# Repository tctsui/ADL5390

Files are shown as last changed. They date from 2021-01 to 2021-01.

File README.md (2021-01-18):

# ADL5390
This is a PCB design for an RF vector multiplier ADL5390 from Analog Devices. The functionality and design of this board is similar to the original evaluation board design. The purpose of this board is to solve the problem of crosstalk between the I-channel and the Q-channel in the original evaluation board. The main modification is the use of differential inputs on the two-channels with  a 180 hybrid coupler SYPJ-2-33+.
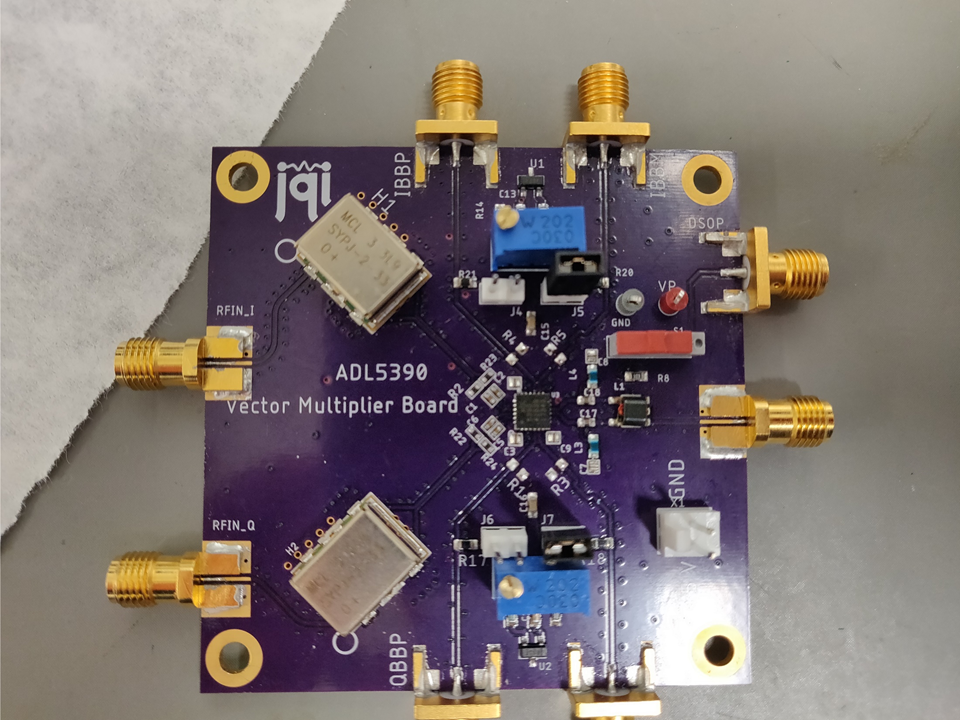
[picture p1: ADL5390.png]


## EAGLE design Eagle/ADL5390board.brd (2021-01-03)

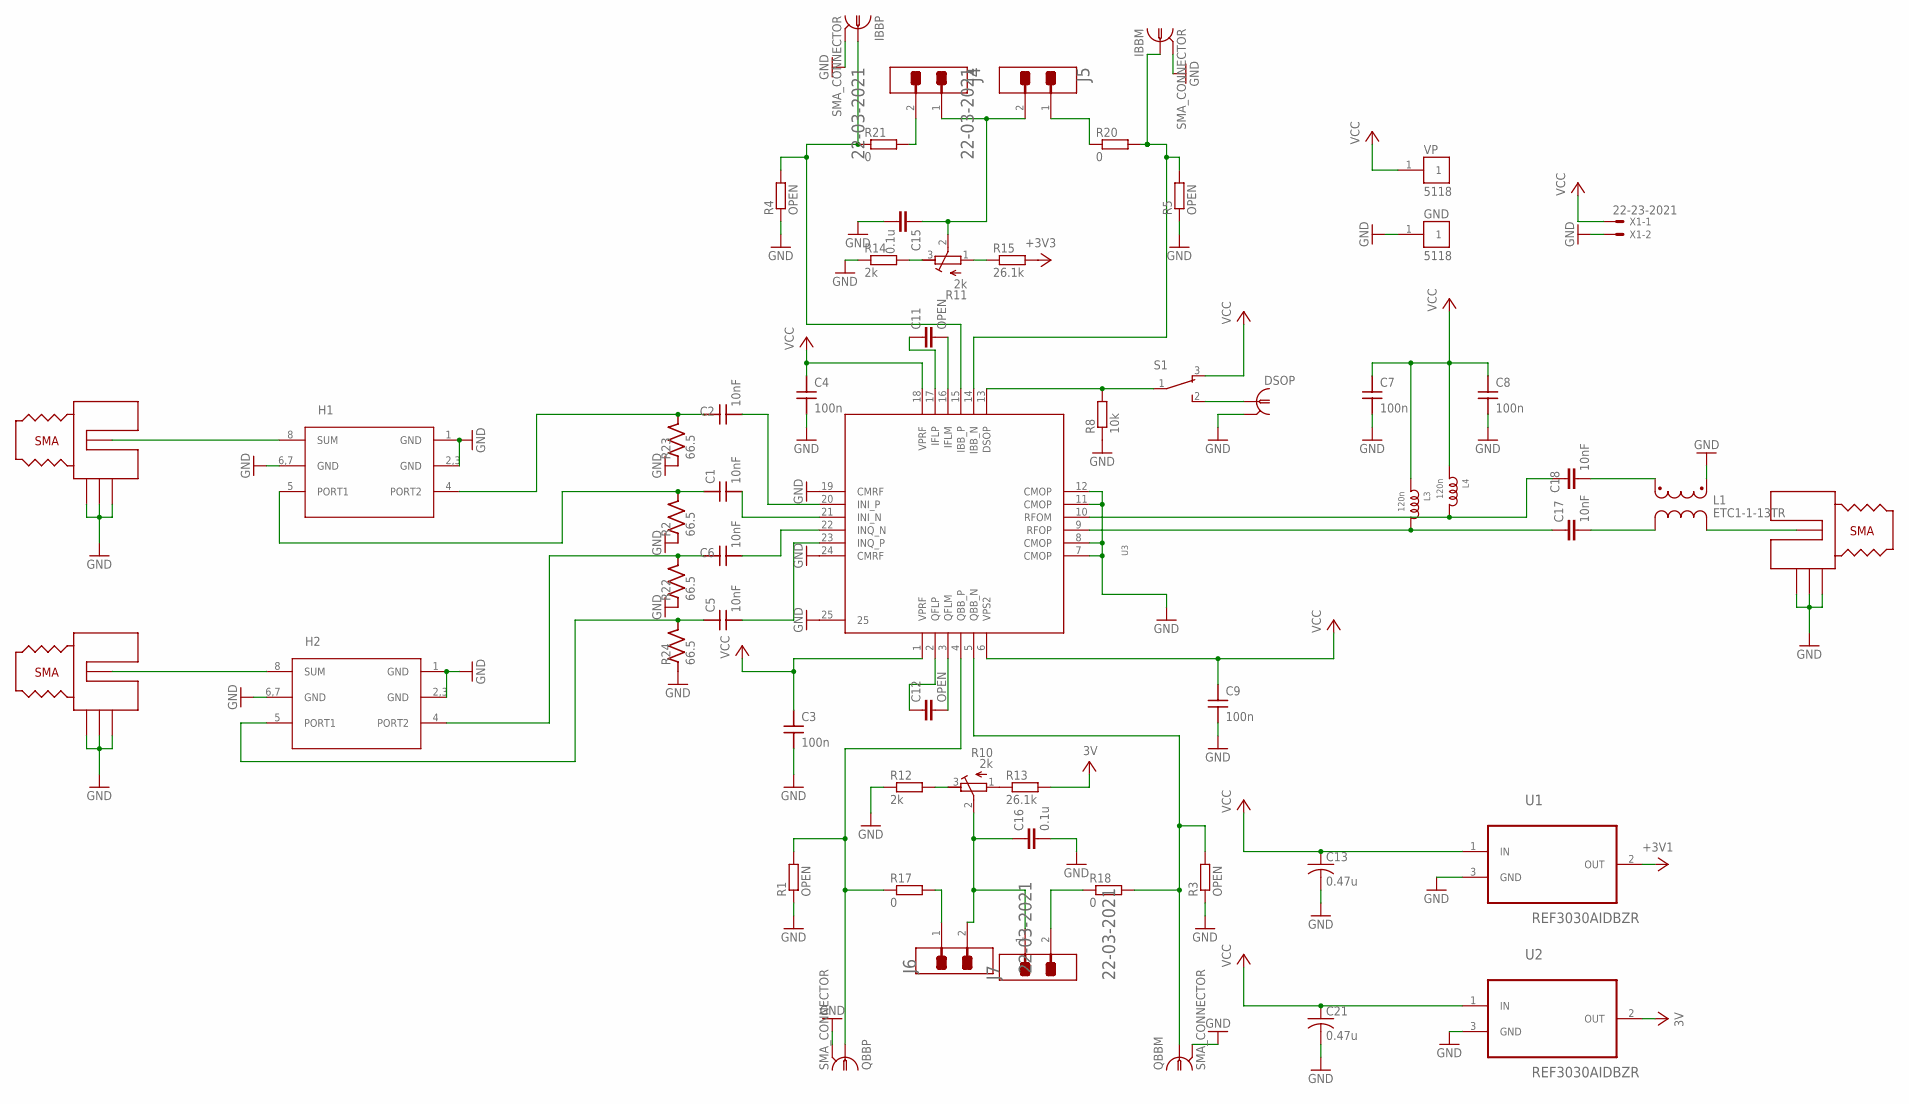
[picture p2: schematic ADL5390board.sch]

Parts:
C1, C2, C5, C6: 10nF; C_MLCC_0402; PARTNO C1005C0G1H102J050BA; DIGIKEY 445-6846-1-ND
C3, C4, C7, C8, C9: 100n; C_MLCC_0204; PARTNO EWK105C6104MPHF; DIGIKEY 587-5138-1-ND
C11, C12: OPEN; C0603
C13, C21: 0.47u; C0603; PARTNO CL10B474KA8NFNC; DIGIKEY 1276-2082-1-ND
C15, C16: 0.1u; C0603; PARTNO CL10B104KA8NNNC; DIGIKEY 1276-1006-1-ND
C17, C18: 10nF; C0402; PARTNO C1005C0G1H102J050BA; DIGIKEY 445-6846-1-ND
DSOP: SMA_CONNECTOR; QKDLAB_JOSH_MECHANICAL_JOHNSON_SMA_EDGE_LAUNCH_142-0701-851
GND: 5118; TP_5118; PARTNO 5118; DIGIKEY 36-5118-ND
H1, H2: SYPJ-2-33+; PL-274
IBBM: SMA_CONNECTOR; QKDLAB_JOSH_MECHANICAL_JOHNSON_SMA_EDGE_LAUNCH_142-0701-851; DIGIKEY J658-ND
IBBP: SMA_CONNECTOR; QKDLAB_JOSH_MECHANICAL_JOHNSON_SMA_EDGE_LAUNCH_142-0701-851; DIGIKEY J658-ND
J1, J2, J3: QKDLAB_JOSH_MECHANICAL_JOHNSON_SMA_18GHZ_142-0761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; QKDLAB_JOSH_MECHANICAL_JOHNSON_SMA_18GHZ_4-LAYER_142-0761-8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; PARTNO 901-10511-2; DIGIKEY ARF2499-ND
J4, J5, J6, J7: MOLEX_22-03-2021MOLEX_22-03-2021_0_0; MOLEX_22-03-2021_0
L1: ETC1-1-13TR; SM22; DIGIKEY 1465-1217-1-ND
L3, L4: 120n; R0603; PARTNO LQW18ASR12G0CD; DIGIKEY 490-LQW18ASR12G0CDCT-ND
QBBM: SMA_CONNECTOR; QKDLAB_JOSH_MECHANICAL_JOHNSON_SMA_EDGE_LAUNCH_142-0701-851; DIGIKEY J658-ND
QBBP: SMA_CONNECTOR; QKDLAB_JOSH_MECHANICAL_JOHNSON_SMA_EDGE_LAUNCH_142-0701-851; DIGIKEY J658-ND
R1, R3, R4, R5: OPEN; R0603; PARTNO CRCW06030000Z0EA; DIGIKEY 541-0.0GCT-ND
R2, R22, R23, R24: 66.5; R_0402; PARTNO ERJ-2RKF66R5X; DIGIKEY P66.5LDKR-ND
R8: 10k; R0603; PARTNO ERA-3AEB103V; DIGIKEY P10KDBCT-ND
R10, R11: 2k; RTRIM3296W; PARTNO PV36W202C01B00; DIGIKEY 490-2880-ND
R12, R14: 2k; R0603; PARTNO ERA-3AEB202V; DIGIKEY P2.0KDBCT-ND
R13, R15: 26.1k; R0603; PARTNO ERA-3AEB2612V; DIGIKEY P26.1KDBCT-ND
R17, R18, R20, R21: 0; R0603; PARTNO CRCW06030000Z0EA; DIGIKEY 541-0.0GCT-ND
S1: 450301014042; DIGIKEY 450301014042-ND
U1, U2: REF3030AIDBZR; SOT95P237X112-3N
U3: ADL5390_ADL5390; PARTNO ADL5390ACPZ-REEL7; DIGIKEY ADL5390ACPZ-REEL7CT-ND
VP: 5118; TP_5118; PARTNO 5000; DIGIKEY 36-5000-ND
X1: 22-23-2021

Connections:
+3V3: R15.2, U1.2 (OUT)
DSOP: R8.2, S1.1, U3.13 (DSOP)
GND: C3.P$2 (2), C4.P$2 (2), C7.P$2 (2), C8.P$2 (2), C9.P$2 (2), C13.2, C15.2, C16.2, C21.2, DSOP.P$2 (2), DSOP.P$3 (2), DSOP.P$4 (2), DSOP.P$5 (2), GND.1, H1.1 (GND), H1.2,3 (GND), H1.6,7 (GND), H2.1 (GND), H2.2,3 (GND), H2.6,7 (GND), IBBM.P$2 (2), IBBM.P$3 (2), IBBM.P$4 (2), IBBM.P$5 (2), IBBP.P$2 (2), IBBP.P$3 (2), IBBP.P$4 (2), IBBP.P$5 (2), J1.P$2 (GND), J1.P$3 (GND), J1.P$4 (GND), J2.P$2 (GND), J2.P$3 (GND), J2.P$4 (GND), J3.P$2 (GND), J3.P$3 (GND), J3.P$4 (GND), L1.1, QBBM.P$2 (2), QBBM.P$3 (2), QBBM.P$4 (2), QBBM.P$5 (2), QBBP.P$2 (2), QBBP.P$3 (2), QBBP.P$4 (2), QBBP.P$5 (2), R1.1, R2.P$1 (1), R3.1, R4.1, R5.1, R8.1, R12.1, R14.1, R22.P$1 (1), R23.P$1 (1), R24.P$1 (1), U1.3 (GND), U2.3 (GND), U3.7 (CMOP), U3.8 (CMOP), U3.11 (CMOP), U3.12 (CMOP), U3.19 (CMRF), U3.24 (CMRF), U3.25, X1.2
IBB_N: IBBM.P$1 (1), R5.2, R20.2, U3.14 (IBB_N)
IBB_P: IBBP.P$1 (1), R4.2, R21.1, U3.15 (IBB_P)
IFL_N: C11.2, U3.16 (IFLM)
IFL_P: C11.1, U3.17 (IFLP)
INI_N: C1.P$2 (2), U3.21 (INI_N)
INI_P: C2.P$2 (2), U3.20 (INI_P)
INQ_N: C6.P$2 (2), U3.22 (INQ_N)
INQ_P: C5.P$2 (2), U3.23 (INQ_P)
IN_N: H2.8 (SUM), J2.P$1 (SIG)
IN_P: H1.8 (SUM), J1.P$1 (SIG)
unnamed: R11.1 (A), R15.1
unnamed: R11.3 (E), R14.2
unnamed: C15.1, J4.1, J5.2, R11.2 (S)
unnamed: J4.2, R21.2
unnamed: J5.1, R20.1
unnamed: J6.1, R17.2
unnamed: J7.2, R18.1
unnamed: C16.1, J6.2, J7.1, R10.2 (S)
unnamed: R10.3 (E), R12.2
unnamed: R10.1 (A), R13.1
unnamed: C18.2, L1.5
unnamed: C17.2, L1.4
unnamed: J3.P$1 (SIG), L1.3
unnamed: DSOP.P$1 (1), S1.2
QBB_N: QBBM.P$1 (1), R3.2, R18.2, U3.5 (QBB_N)
QBB_P: QBBP.P$1 (1), R1.2, R17.1, U3.4 (QBB_P)
QFL_N: C12.2, U3.3 (QFLM)
QFL_P: C12.1, U3.2 (QFLP)
RFINI_N: C1.P$1 (1), H1.5 (PORT1), R2.P$2 (2)
RFINI_P: C2.P$1 (1), H1.4 (PORT2), R23.P$2 (2)
RFINQ_N: C6.P$1 (1), H2.4 (PORT2), R22.P$2 (2)
RFINQ_P: C5.P$1 (1), H2.5 (PORT1), R24.P$2 (2)
RFO_N: C18.1, L4.2, U3.10 (RFOM)
RFO_P: C17.1, L3.2, U3.9 (RFOP)
V+: R13.2, U2.2 (OUT)
VCC: C3.P$1 (1), C4.P$1 (1), C7.P$1 (1), C8.P$1 (1), C9.P$1 (1), C13.1, C21.1, L3.1, L4.1, S1.3, U1.1 (IN), U2.1 (IN), U3.1 (VPRF), U3.6 (VPS2), U3.18 (VPRF), VP.1, X1.1

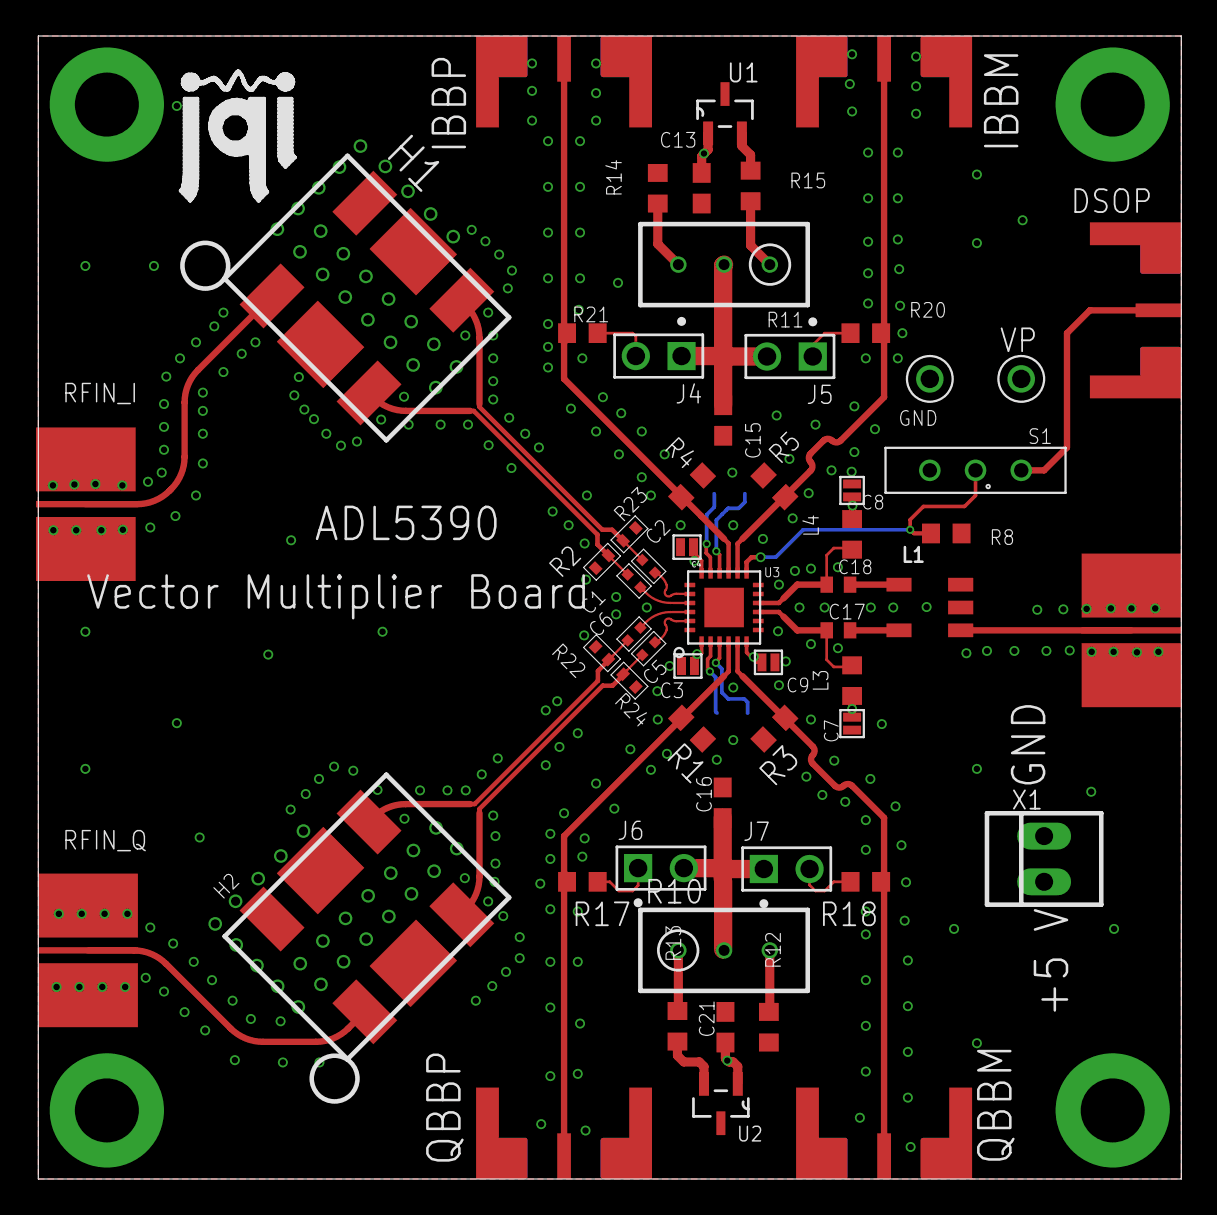
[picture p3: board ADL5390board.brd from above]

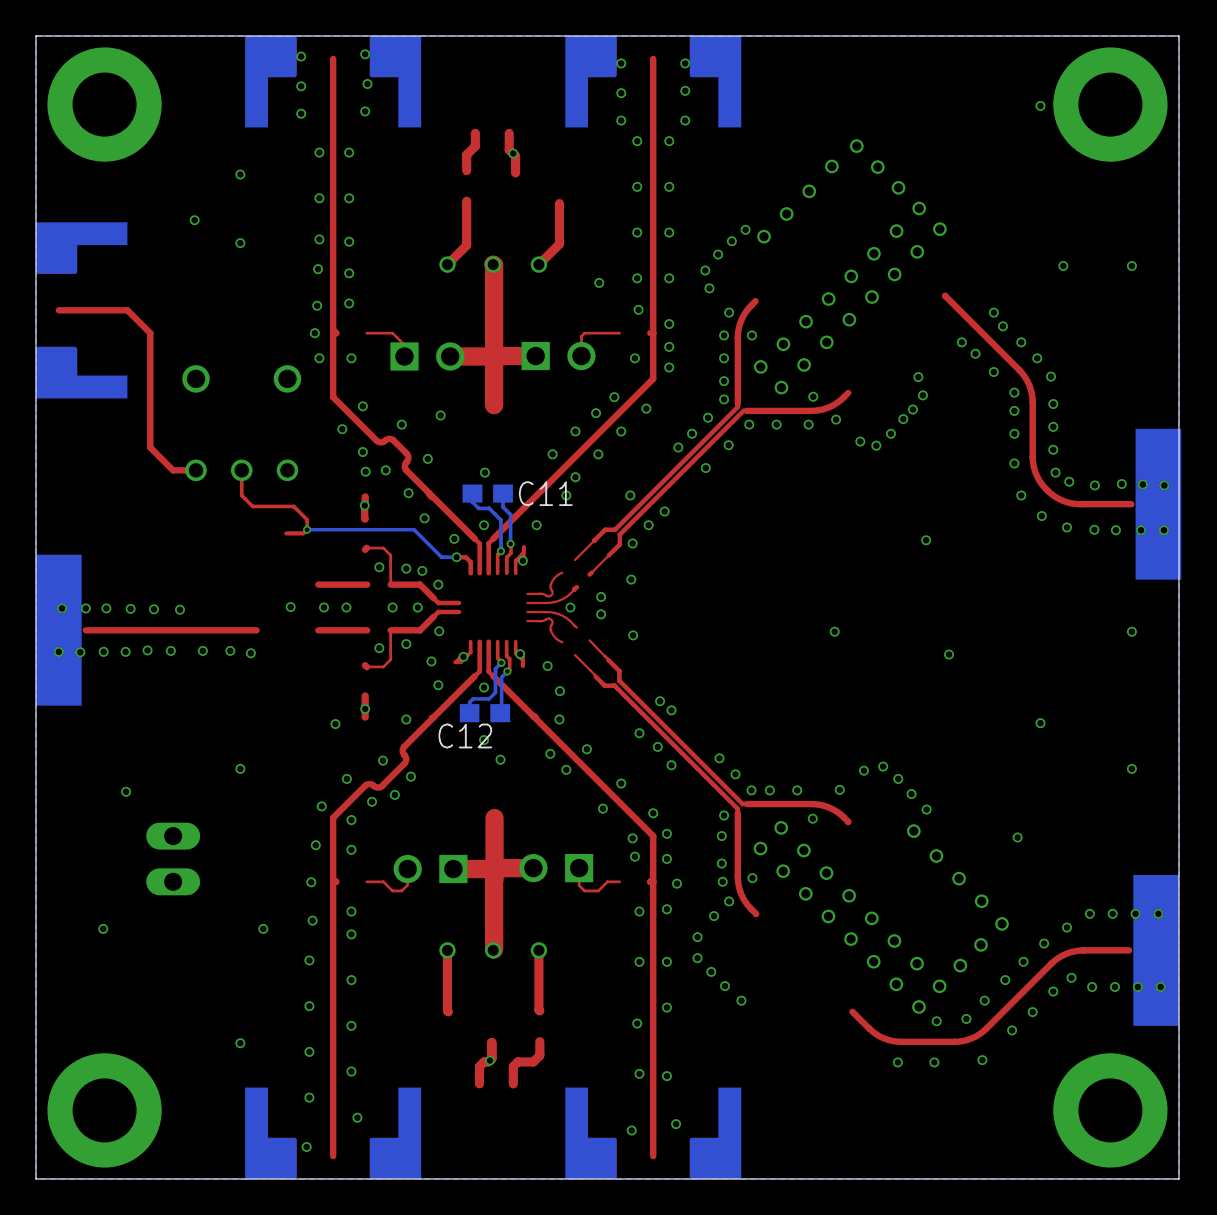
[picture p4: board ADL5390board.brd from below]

Board: 4 copper layers, 63.5 x 63.5 mm, 61 parts (2 on the bottom side), 39 nets.

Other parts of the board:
U$4: JQI_LOGO_POSITIVE-SILKSCREEN
